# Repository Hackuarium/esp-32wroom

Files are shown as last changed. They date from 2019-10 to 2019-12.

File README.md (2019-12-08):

| #  | Name | A | SPI | HS | I2C | Touch | Used | RTC |
|----|---|---|---|---|-----|---|---|---|
| 1  | GND | | | | | | | |
| 2  | 3V3 | | | | | | | |
| 3  | EN | | | | | | | |
| 4  | SENSOR_VP/IO36 | A0 | | | | | | RTC_GPIO0  |
| 5  | SENSOR_VN/IO39 | A3 | | | | | Charging | RTC_GPIO3  |
| 6  | IO34 | A6 | | | | | OneWire1 | RTC_GPIO4  |
| 7  | IO35 | A7 | | | | | OneWire2 | RTC_GPIO5  |
| 8  | IO32 | A4 | | | | T9 | Ext3 | RTC_GPIO9  |
| 9  | IO33 | A5 | | | | T8 | Ext4 | RTC_GPIO8  |
| 10 | IO25 | A18 * | | | | | Ext1 | RTC_GPIO6  |
| 11 | IO26 | A19 * | | | | | Ext2 | RTC_GPIO7  |
| 12 | IO27 | A17 * | | | | T7 | ADC battery | RTC_GPIO17 |
| 13 | IO14 | A16 * | HSPICLK | HS2_CLK | | T6 | Blue | RTC_GPIO16 |
| 14 | IO12 | A15 * | HSPIQ | HS2_DATA2  | | T5 | Red | RTC_GPIO15 |
| 15 | GND | | | | | | | |
| 16 | IO13 | A14 * | HSPID | HS2_DATA3  | | T4 | Green | RTC_GPIO14 |
| 17 | SHD/SD2 | | SPIHD | HS1 | | | | |
| 18 | SWP/SD3 | | SPIWP | | | | | |
| 19 | SCS/CMD | | SPICS0  | | | | | |
| 20 | SCK/CLK | | SPICLK  | | | | | |
| 21 | SDO/SD0 | | SPIQ | | | | | |
| 22 | SDI/SD1 | | SPID | | | | | |
| 23 | IO15 | A13 * | HSPICS0 | | | T3 | White | RTC_GPIO13 |
| 24 | IO2 | A12 * | HSPIWP  | | | T2 | RESERVED | RTC_GPIO12 |
| 25 | IO0 | A11 * | | | | T1 | Prog | RTC_GPIO11 |
| 26 | IO4 | A10 * | HSPIHD  | HS2_DATA1  | | T0 | OneWire1 | RTC_GPIO10 |
| 27 | IO16 | | | HS1_DATA4  | | | | |
| 28 | IO17 | | | HS1_DATA5  | | | | |
| 29 | IO5 | | VSPICS0 | HS1_DATA6  | | | | |
| 30 | IO18 | | VSPICLK | HS1_DATA7  | | | Blink LED | |
| 31 | IO19 | | VSPIQ | | | | | |
| 32 | NC | | | | | | | |
| 33 | IO21 | | VSPIHD  | | SDA | | SDA | |
| 34 | RXD0 | | | | | | RX | |
| 35 | TXD0 | | | | | | TX | |
| 36 | IO22 | | VSPIWP  | | SCL | | SCL | |
| 37 | IO23 | | VSPID | HS1_STROBE | | | | |
| 38 | GND | | | | | | | |

*: not usable with WIFI

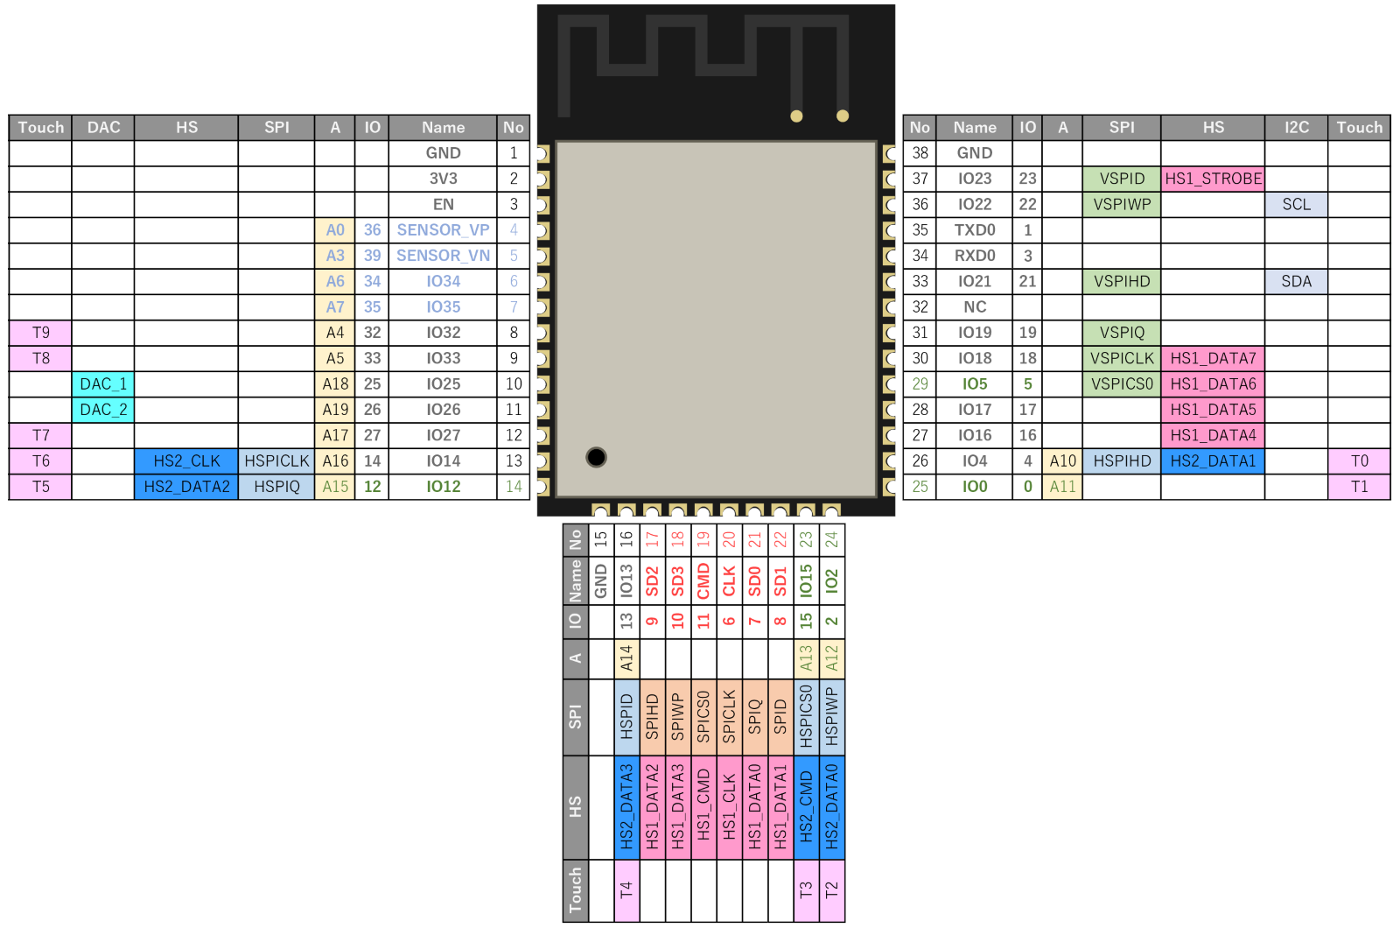
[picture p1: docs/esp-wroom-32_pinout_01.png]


## ESP32-Wroom32 datasheet

https://www.espressif.com/sites/default/files/documentation/esp32-wroom-32_datasheet_en.pdf

## Official Espressif hardware design guidelines

https://www.espressif.com/sites/default/files/documentation/esp32_hardware_design_guidelines_en.pdf

## Really DIY ESP32 board

https://www.instructables.com/id/DIY-ESP32-Development-Board-ESPer/

## Programming an ESP32 from Arduino IDE

Start by installing the ESP32 board in Arduino IDE
https://randomnerdtutorials.com/installing-the-esp32-board-in-arduino-ide-mac-and-linux-instructions/ (Mac/Linux)
https://randomnerdtutorials.com/installing-the-esp32-board-in-arduino-ide-windows-instructions/ (Windows)

Getting started with ESP32 (including blink example)
https://randomnerdtutorials.com/getting-started-with-esp32/

Some debug information
https://github.com/espressif/esptool/wiki/ESP32-Boot-Mode-Selection

## Flashing board

In Arduino IDE, select "ESP32 Wrover module" (>tools>boards), connect the UART programmer to the board (make sure it is in the right orientation), select the corresponding port (>tools>port). Write a simple sketch (for example blink using pin18 for the red light), and upload it to the board, after seeing the "Connecting..." message in the lower windows of Arduino IDE, press both buttons (PROG and RESET), release the "RESET" button first and then release the "BOOT" button, the upload should start. After this, press reset so that the latest code runs on the board (you should see the red light blinking).

To avoid worrying about pressing the button, connect 10 uF electrolytic capacitor between the EN pin and GND (may work or not depending on boards...)
(https://randomnerdtutorials.com/solved-failed-to-connect-to-esp32-timed-out-waiting-for-packet-header/)

## Resources

Many ESP32 tutorials/projects are available at Random Nerd Tutorials (web-based, sensor-based, data logging, deep sleep...):
https://randomnerdtutorials.com/projects-esp32/

Schema for a dev kit: https://dl.espressif.com/dl/schematics/esp32_devkitc_v4-sch.pdf

Ultra low power tips for ESP32: http://iot-bits.com/ultra-low-power-design-esp32-10-tips/

## FreeRTOS

## Functions

- RGBW
- PCA9685 + 4 x BSP75
- WS2812 : addressable led
- Luminosity: TCS3400 or VEML6040 or VEML7700
- Pressure: MS5637
- Humidity / Temperature: ChipCAP2 or Si7021
- Power monitoring

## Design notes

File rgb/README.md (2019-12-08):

## RGB module

This module allows to drive 4 RGBW led strips.

We should not use over 5A/12v of current (due to the power plug) so it means that each strip may have up to 40 LEDs.

Each channel is planned for 1A max which means 150 LEDs (in 12V) per channel (but with the global limit of 5A.

## Available variables

| index | register | description | min | max | |
|---|---|---|-----|-----|---|
| 0 | A | Channel 1: red | 0 | 255 | R / W |
| 1 | B | Channel 1: green | 0 | 255 | R / W |
| 2 | C | Channel 1: blue  | 0 | 255 | R / W |
| 3 | D | Channel 1: white | 0 | 255 | R / W |
| 4 | E | Channel 2: red | 0 | 255 | R / W |
| 5 | F | Channel 2: green | 0 | 255 | R / W |
| 6 | G | Channel 2: blue  | 0 | 255 | R / W |
| 7 | H | Channel 2: white | 0 | 255 | R / W |
| 8 | I | Channel 3: red | 0 | 255 | R / W |
| 9 | J | Channel 3: green | 0 | 255 | R / W |
| 10 | K | Channel 3: blue  | 0 | 255 | R / W |
| 11 | L | Channel 3: white | 0 | 255 | R / W |
| 12 | M | Channel 4: red | 0 | 255 | R / W |
| 13 | N | Channel 4: green | 0 | 255 | R / W |
| 14 | O | Channel 4: blue  | 0 | 255 | R / W |
| 15 | P | Channel 4: white | 0 | 255 | R / W |
| 16 | Q | Program | | | R / W |
| 17 | R | Intensity | | | R / W |
| 18 | S | Speed | | | R / W |
| 19 | T | Humidity | | | Read only |
| 20 | U | Pressure | | | Read only |
| 21 | V | Temperature | | | Read only |
| 22 | W | Light sensor R | | | Read only |
| 23 | X | Light sensor G | | | Read only |
| 24 | Y | Light sensor B | | | Read only |
| 25 | Z | Light sensor IR  | | | Read only |

## General parameters

- Wifi
  - SSID
  - username
  - password
- MQTT
  - server
  - username / password ???s
- Topic
  - Name (alias to the mac address)

When a device boots for the first time it will by default listen to the 'Topic' that corresponds to its mac address.

## Setting / reading variables

Command may be send using mqtt. The device will subscribe to event

| Command  | Description |
|---|---|
| A | Read register A |
| A5 | Set the value 5 to register A |
| C6,7,8,9 | Set the value 6 to C, 7 to D, 8 to E and 9 to F |

Lowercases are used to send commands

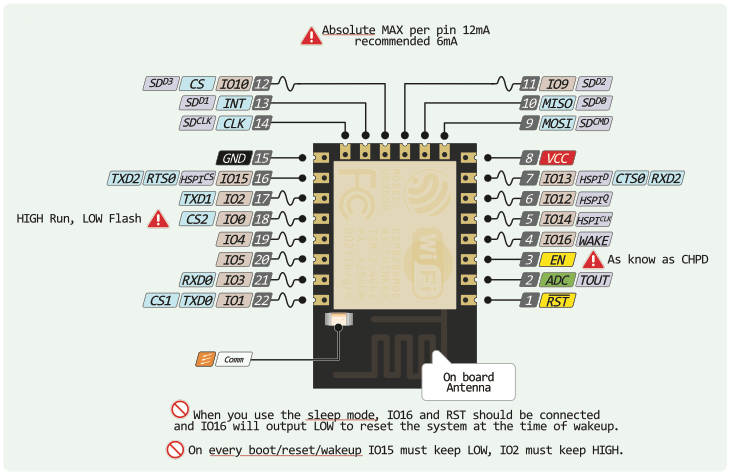
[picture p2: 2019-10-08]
docs/esp12e-pinout.png

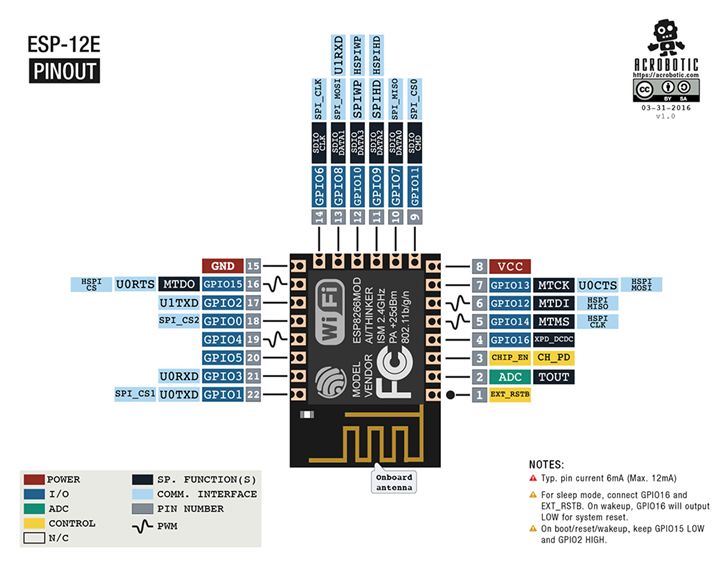
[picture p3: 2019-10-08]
docs/FIDTRK6JH8JBTII.LARGE.jpg

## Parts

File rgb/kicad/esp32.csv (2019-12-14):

Id | Designator | Package | Quantity | Designation | Supplier and ref
1 | J4 | pad_0.1x0.3_hole | 1 | G1
2 | J3 | pad_0.1x0.3_hole | 1 | R1
3 | J2,J22,J17,J11 | pad_0.1x0.3_hole | 4 | +12V
4 | J26,J10 | pad_0.1x0.3_hole | 2 | W1
5 | J25 | pad_0.1x0.3_hole | 1 | B4
6 | J24 | pad_0.1x0.3_hole | 1 | G4
7 | J23 | pad_0.1x0.3_hole | 1 | R4
8 | J21 | pad_0.1x0.3_hole | 1 | W3
9 | J20 | pad_0.1x0.3_hole | 1 | B3
10 | J19 | pad_0.1x0.3_hole | 1 | G3
11 | J18 | pad_0.1x0.3_hole | 1 | R3
12 | J16 | pad_0.1x0.3_hole | 1 | W2
13 | J14 | pad_0.1x0.3_hole | 1 | B2
14 | J13 | pad_0.1x0.3_hole | 1 | G2
15 | J12 | pad_0.1x0.3_hole | 1 | R2
16 | J9 | pad_0.1x0.3_hole | 1 | B1
17 | U1 | ESP32-WROOM-32U | 1 | ESP32-WROOM-32U
18 | D3,D1 | D_SOD-123 | 2 | D_Schottky
19 | U6 | TO-92_Inline | 1 | DS18B20
20 | U4 | TSSOP-28_4.4x9.7mm_P0.65mm | 1 | PCA9685PW
21 | Q16,Q15,Q14,Q13,Q12,Q11,Q10,Q9,Q8,Q7,Q6,Q5,Q4,Q3,Q2,Q1 | SOT-23 | 16 | ZXMS6004
22 | U8 | Broadcom_DFN-6_2x2mm_P0.65mm | 1 | TCS3400
23 | R17 | R_0805_2012Metric_Pad1.15x1.40mm_HandSolder | 1 | 4.7k
24 | R16,R5,R2 | R_0805_2012Metric_Pad1.15x1.40mm_HandSolder | 3 | 10k
25 | D8 | D_SOD-123 | 1 | B240A
26 | U5 | SOT-23-6_Handsoldering | 1 | ACT4088
27 | R15 | R_0805_2012Metric_Pad1.15x1.40mm_HandSolder | 1 | 16.23k
28 | R14 | R_0805_2012Metric_Pad1.15x1.40mm_HandSolder | 1 | 49.9k
29 | L2 | L_0805_2012Metric_Pad1.15x1.40mm_HandSolder | 1 | 4.7µH
30 | C13 | C_0805_2012Metric_Pad1.15x1.40mm_HandSolder | 1 | 22µF
31 | C8 | C_0805_2012Metric_Pad1.15x1.40mm_HandSolder | 1 | 22nF
32 | C9 | C_0805_2012Metric_Pad1.15x1.40mm_HandSolder | 1 | 10µF
33 | D4,D2 | LED_0805_2012Metric_Pad1.15x1.40mm_HandSolder | 2 | LED
34 | R4 | R_0805_2012Metric_Pad1.15x1.40mm_HandSolder | 1 | 499
35 | C1 | C_0805_2012Metric_Pad1.15x1.40mm_HandSolder | 1 | 100nF
36 | C2,C4,C3 | C_0805_2012Metric_Pad1.15x1.40mm_HandSolder | 3 | 10uF
37 | SW1 | SW_SPST_PTS645 | 1 | RESET
38 | SW2 | SW_SPST_PTS645 | 1 | PROG
39 | J6,J8,J7,J5 | MountingHole_3.2mm_M3 | 4 | hole
40 | TP4 | TestPoint_2Pads_Pitch2.54mm_Drill0.8mm | 1 | 3.3V
41 | J1 | BarrelJack_Horizontal | 1 | 5 / 12V
42 | U3 | DFN-6-1EP_3x3mm_P1mm_EP1.5x2.4mm | 1 | Si7020-A20
43 | J15 | PinHeader_1x06_P2.54mm_Vertical | 1 | CONN FT232RL
44 | U2 | MS5637 | 1 | MS5637

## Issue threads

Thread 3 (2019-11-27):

Change power supply

lpatiny, 2019-11-27:
https://www.mouser.ch/datasheet/2/412/ACT4088_Datasheet-1627529.pdf

ACT4088 would allow to directly generate 3.3v from anything between 3 to 30v

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

lpatiny, 2019-11-29:
Add 2 modules. Xv -> 5v (to charge battery) and 3.7v -> 4.2v to 3.3v.

Closed 2019-11-30.

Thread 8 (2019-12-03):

ADC for battery should be moved

lpatiny, 2019-12-03:
Should go on SENSOR_VN/IO39 because otherwise can not work when WIFI is on

Closed 2019-12-08.

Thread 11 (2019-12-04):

Change footprint for inductor 4.7uH

lpatiny, 2019-12-04:
Ideally we should plan a power supply that can provide 1A at least just to be sure we can get 500mA on the long term.

lpatiny, 2019-12-08:
0805 seems ok and larger footprint would not lead to a reduction of price

Closed 2019-12-08.

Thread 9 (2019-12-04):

Change footprint of 22uF to 1206

lpatiny, 2019-12-04:
In order to reduce the price of the component ...

lpatiny, 2019-12-08:
It is not necessary. There are plenty of 22uF in 0805 that are ok for this power supply:

https://www.mouser.ch/Passive-Components/Capacitors/Ceramic-Capacitors/MLCCs-Multilayer-Ceramic-Capacitors/Multilayer-Ceramic-Capacitors-MLCC-SMD-SMT/_/N-bkrdv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

Closed 2019-12-08.

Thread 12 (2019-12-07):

Change to step down that works from 3v

lpatiny, 2019-12-07:

lpatiny, 2019-12-08:
Will not be done. We expect at least 3.7v as input for the LDO.
See: https://github.com/Hackuarium/esp-32wroom/issues/13

Closed 2019-12-08.

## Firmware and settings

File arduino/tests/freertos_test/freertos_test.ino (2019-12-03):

/********* 
Adapted from https://randomnerdtutorials.com  
*********/

TaskHandle_t Task1;
TaskHandle_t Task2;

// LED pins
const int led1 = 18;
//const int led2 = 4;

void setup() {
  Serial.begin(9600); 
  pinMode(led1, OUTPUT);
 // pinMode(led2, OUTPUT);

  //create a task that will be executed in the Task1code() function, with priority 1 and executed on core 0
  xTaskCreatePinnedToCore(
                    Task1code,   /* Task function. */
                    "Task1",     /* name of task. */
                    10000,       /* Stack size of task */
                    NULL,        /* parameter of the task */
                    2,           /* priority of the task */
                    &Task1,      /* Task handle to keep track of created task */
                    0);          /* pin task to core 0 */                  
  delay(500); 

  //create a task that will be executed in the Task2code() function, with priority 1 and executed on core 1
  xTaskCreatePinnedToCore(
                    Task2code,   /* Task function. */
                    "Task2",     /* name of task. */
                    10000,       /* Stack size of task */
                    NULL,        /* parameter of the task */
                    1,           /* priority of the task */
                    &Task2,      /* Task handle to keep track of created task */
                    0);          /* pin task to core 1 */
    delay(500); 
}

//Task1code: blinks a LED every 500 ms, print core used every second
void Task1code( void * pvParameters ){
  Serial.print("Task1 running on core ");
  Serial.println(xPortGetCoreID());

  while(1){
    Serial.print("Task1 running on core ");
    Serial.println(xPortGetCoreID());
    digitalWrite(led1, HIGH);
    delay(500);
    digitalWrite(led1, LOW);
    delay(500);
  } 
}

//Task2code: print task name and core used every 800 ms
void Task2code( void * pvParameters ){
  Serial.print("Task2 running on core ");
  Serial.println(xPortGetCoreID());
//
//  for(;;){
//    digitalWrite(led2, HIGH);
//    delay(700);
//    digitalWrite(led2, LOW);
//    delay(700);
//  }
    while(1) {
      Serial.print("Task2 running on core ");
  Serial.println(xPortGetCoreID());
  delay(800);
      } // tasks must have an infinite loop
    // OR get killed once done with vTaskDelete(NULL);
}

void loop() {
  
}

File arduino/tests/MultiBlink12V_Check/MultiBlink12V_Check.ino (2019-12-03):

void setup() {
  Serial.begin(9600);
  //analogReference(); 
  pinMode(12, OUTPUT);
  pinMode(13, OUTPUT);
  pinMode(14, OUTPUT);
  pinMode(15, OUTPUT);
}

void loop() {
  Serial.println("Blinking IO 12 to 15 1sec ON, 1 sec OFF");
  digitalWrite(12, HIGH);
  digitalWrite(13, HIGH);
  digitalWrite(14, HIGH);
  digitalWrite(15, HIGH);
  delay(1000);
  digitalWrite(12, LOW);
  digitalWrite(13, LOW);
  digitalWrite(14, LOW);
  digitalWrite(15, LOW);
  delay(1000);
}

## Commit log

2019-10-08 copy of esp8266
    [MCP1703-33.kicad_pcb, MCP1703-33.sch, MCP1703-50.sch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]
2019-10-08 work in progress
    [MCP1703-33.sch, MCP1703-50.sch, MCP73831.sch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]
2019-10-22 chore: working on pcb
    [esp32.kicad_pcb, esp32.sch]
2019-10-22 feat: pcb v1
    [MCP1703-33.sch, MCP1703-50.sch, MCP73831.sch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]
2019-11-06 feat: add RGB board (work in progress)
    [MCP1703-33.kicad_pcb, MCP1703-33.sch, MCP1703-50.sch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]
2019-11-09 docs: add link to dev schematic
2019-11-29 docs: correct pin mapping T4
2019-11-29 docs: include pin mapping image
2019-11-30 feat: add ACT4088-50.sch
    [ACT4088-50.sch]
2019-11-30 chore: refactor for relative path and prepare 'hacki' subproject
    [ACT4088-50.sch, MCP1703-33.kicad_pcb, MCP1703-33.sch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]
2019-11-30 feat: update power supply close https://github.com/Hackuarium/esp-32wroom/issues/3
    [ACT4088-33.sch, ACT4088-50.sch, MCP1703-33.kicad_pcb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]
2019-11-30 fix: pullup on reset close: https://github.com/Hackuarium/esp-32wroom/issues/1
    [esp32.kicad_pcb, esp32.sch]
2019-11-30 feat: add light and temperature sensors. closes https://github.com/Hackuarium/esp-32wroom/issues/6 and https://github.com/Hackuarium/esp-32wroom/issues/5
    [esp32.kicad_pcb, esp32.sch]
2019-11-30 fix: not connected pins
    [ACT4088-33.sch, ACT4088-50.sch, esp32.kicad_pcb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]
2019-11-30 chore: improve layout
    [esp32.kicad_pcb]
2019-12-01 chore: working on kicad-rgb
    [esp32.sch]
2019-12-01 chore: add gerber esp32-v110.zip
2019-12-01 chore: refactor and finish rgb
    [ACT4088-33.sch, ACT4088-50.sch, MCP1703-33.kicad_pcb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]
2019-12-01 chore: update rgb
    [MCP1703-33.kicad_pcb, MCP1703-33.sch, MCP1703-50.sch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]
2019-12-03 Update README.md
    Add details in "Flashing board" section
2019-12-03 Make arduino dir + tests subdir containing tests for battery check, blink on 12V and freeRTOS example
2019-12-03 chore: add comment about not usable analogic read
    [esp32.kicad_pcb]
2019-12-03 Update README.md
    add resource for ultra low power settings for esp32
2019-12-06 fix missing ground
    [esp32.kicad_pcb]
2019-12-08 fix: close https://github.com/Hackuarium/esp-32wroom/issues/13
    [ACT4088-50.sch, AP7365-33Y.sch, esp32.kicad_pcb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]
2019-12-08 fix: close https://github.com/Hackuarium/esp-32wroom/issues/8
    [esp32.kicad_pcb, esp32.sch]
2019-12-08 fix: rename One1 to One3
    [esp32.kicad_pcb, esp32.sch]
2019-12-08 chore: update labels
    [esp32.kicad_pcb]
2019-12-08 chore: fix spelling mistake
    [ACT4088-33.sch, ACT4088-50.sch, MCP1703-33.kicad_pcb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]
2019-12-12 chore: move labels
    [esp32.kicad_pcb]
2019-12-14 fix(rgb): add DTR CSR, pullup IO0
    [PCA9685_LED.sch, esp32.csv, esp32.kicad_pcb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]
2019-12-20 update pcb
    [esp32.kicad_pcb]
